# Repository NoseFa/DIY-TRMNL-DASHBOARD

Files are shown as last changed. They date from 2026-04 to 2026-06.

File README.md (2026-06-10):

# Nordic TRMNL

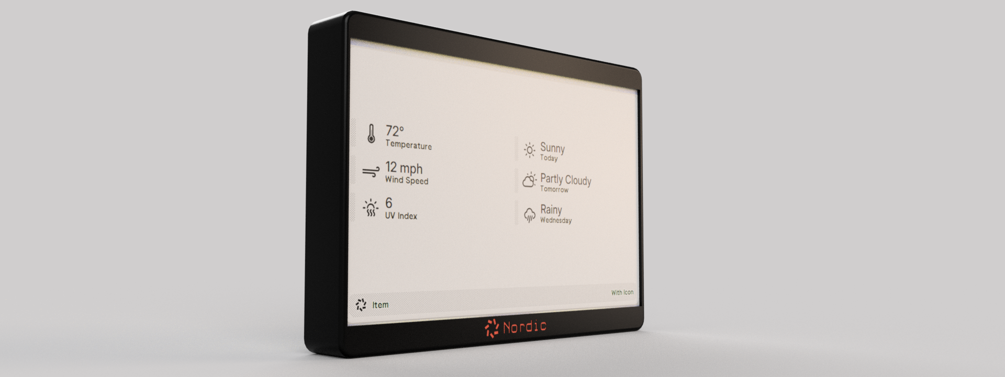
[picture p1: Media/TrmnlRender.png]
Nordic TRMNL 3D render of the nordic TRMNL


A diy dashboard that is built with the TRMNL software in mind. Can display stuff like the your calendar, reminders or the public transit schedule. This repo is only for the hardware side. The TRMNL docs were a huge help in the design process and most of the electronics are based on their suggestions. This project was designed as a part of the Hack Club hardware hackathon FALLOUT where people make hardware projects and get a chance to go to Shenzhen, China. More info available here [Fallout](https://fallout.hackclub.com)!

## Parts

- SEEED studio 7.5" monochrome e-ink display [SeeedStudio](https://www.seeedstudio.com/7-5-Monochrome-ePaper-Display-with-800x480-Pixels-p-5788.html)
- SEEED studio ePaper driver board [SeeedStudio](https://www.seeedstudio.com/ePaper-breakout-Board-for-XIAO-V2-p-6374.html)
- SEEED studio XIAO ESP32-C3 [SeeedStudio](https://www.seeedstudio.com/Seeed-XIAO-ESP32C3-p-5431.html)
- 3D printed [Case](./3Dfiles/)
- M2.5x5mm screws [Aliexpress](https://www.aliexpress.com/item/1005011821173994.html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)
- M2.5 Heated set inserts [Aliexpress](https://www.aliexpress.com/item/1005006838108683.html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)

## Build guide

If you are using the same components the Cad files are here [3D files](./3Dfiles/CaseFiles/). [Case folder](./3Dfiles/CaseFiles/) has ready to print files that have the case parts. Use these if you are just printing the case. The case is designed to be printed in two halves which then are screwed together for the final build. The [full project folder](./3Dfiles/FullProject) has the whole Fusion project including the driver board PCB, ESP-32 and the display. You might want to use this if you want to edit the files. You might also want to adjust some tolerances if your printer has issues with these or you are using different inserts for example. My printer is a pretty budget FDM printer and it didn't have any issues. The two pieces most likely might not fit on the printer at the same time so you might need to print them seperately. I have also included 3D printer files for the [logo pieces](./3Dfiles/CaseFiles/FrontLogo/). If you want to print these seperately. This is what I did because I dont have a multi color printer (This is just if you want the front logo highlighted).

You should start off by printing the [Display holder](./3Dfiles/CaseFiles/DisplayHolder/) and the [Main frame](./3Dfiles/CaseFiles/MainFrame/). These parts are required. The display holder can be printed without supports but the main frame will most likely require them in some areas depending on the orientation you print in. Then you might want to print the logo as well [Logo](./3Dfiles/CaseFiles/FrontLogo/).

After getting the parts printed you can attach the ESP32 to the driver board using the header pins. The display should be installed in the display holder first. You should then install 4 heated inserts in each of the corners of the display holder. The print should have ready made holes for them.

You can then take the main frame and install the heated inserts for the driver board pcb (there are 4 holes). You can then screw in the pcb with the 2.5mm x 5mm screws. If you want to you can add some small pieces of double sided tape to the highlighted corners in the screenshot below. This can make the display fit better but isn't required for the build to work.

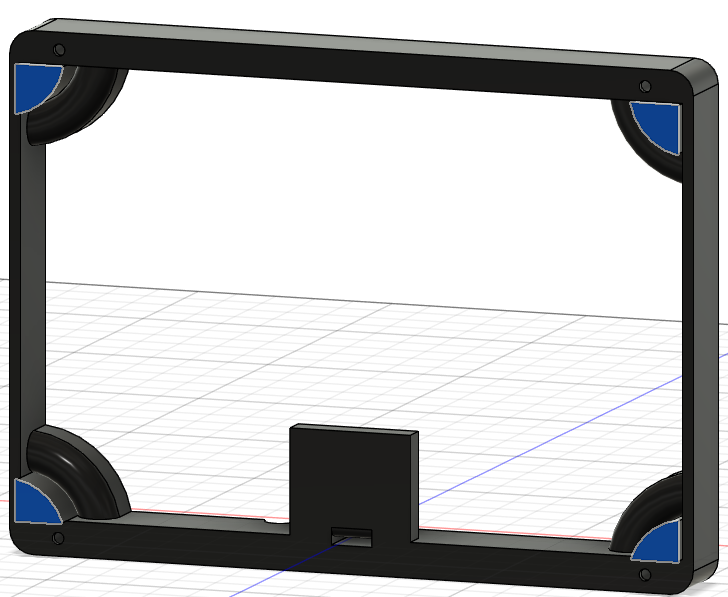
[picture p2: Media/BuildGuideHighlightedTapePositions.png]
Highlighted positions for the double sided tape


After this you can attach the body parts together using the same 2.5mmx5mm screws (you might need a screwdriver with a narrow end to fit) remembering to route the display cable through the slot for it below the pcb holder. If you printed the logo you can attach it using super glue or just press fitting them together.

Now the physical build is done and you can move onto software. You should check the software section for more detailed software instructions. As a TL;DR You can pretty much just use [this tool](https://trmnl.com/flash) to flash the firmware. You should still check the software section for detailed instructions.

If self-hosting follow the guide in the software section or the offical TRMNL guide available in the TRMNL dev [docs](https://docs.trmnl.com/go/diy/byod-s).

If you plan on using TRMNL servers. After flashing the firmware you have to buy access and then claim the device through the site. [Claim your device](https://trmnl.com/claim-a-device).

For mounting the device I used command strips / double sided tape. I think this is better than screws for example because the device is light enough to just be held up with double sided tape. Also making the device attach with screws reliably would be harder and in my opinion overkill.

If you don't have an outlet / power source next to you mounting point you can use a battery. The Seeed e-paper driver board comes with a JST connection to connect a battery and it seems to be pretty easy. I didn't need this since I have an outlet at the perfect spot to plug into and an extra usb-c power source laying around.

## Why does this exist ?

This was a personal project made to make my day to day life easier. Every morning when I wake up I first look at my school schedule then check the time and finally the weather. Of course because of early mornings I usually had to check atleast twice.

So I looked for solutions of displaying the weather while also being able to do other stuff like displaying a calendar or schedule. So I found the TRMNL which was close to a perfect solution for my problem. Unfortunately the official TRMNL OG was a bit too expensive and had some features I didn't need like a battery. So I decided to make my own. My goal for this project was to make something actually useful for me. For this it needed to do atleast 3 things.

1. Show me important information like the weather without having to look at my phone.
2. Wall mountable.
3. Not need to be charged or managed alot after creation.

This was also a project made for Hack Club [Fallout](https://fallout.hackclub.com)! So that was also a motivation behind this project.

## Software

For the software I will start off with explaining the installation process and then move onto some extra info about it.

### Installation

Start off with plugging in the ESP-32 to you computer. You can then open the tool [available here](https://trmnl.com/flash). You can pick the "Seeed studio (XIAO 7.5" ePaper panel)" because it uses the same controller the ESP32-C3.

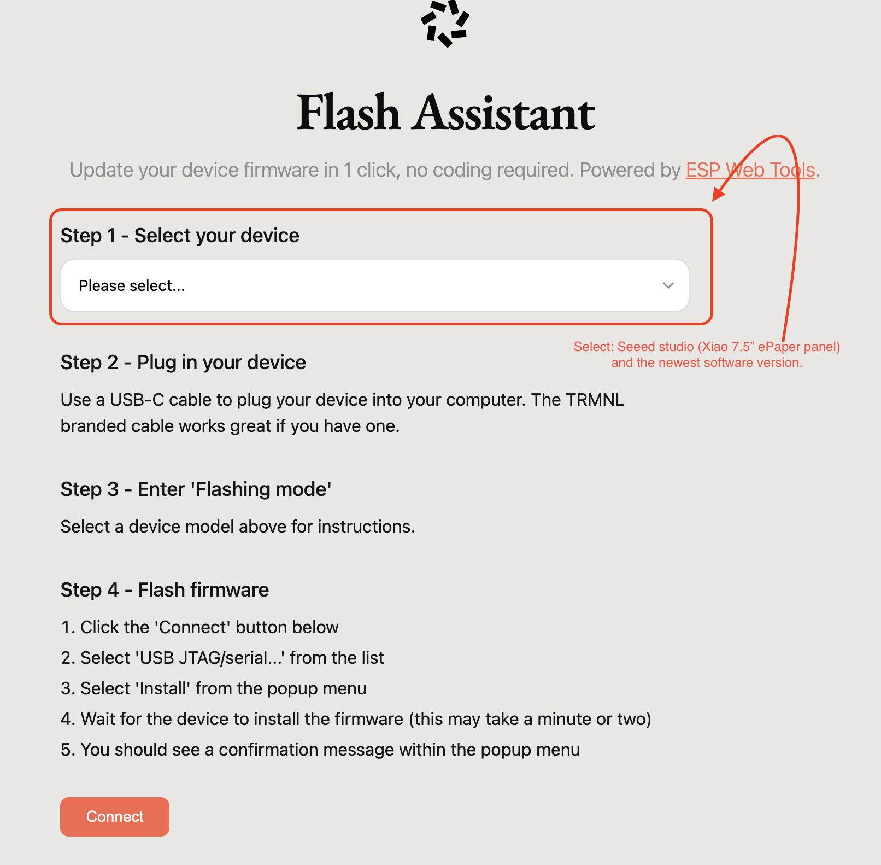
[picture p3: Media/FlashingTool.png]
Flashing tool A screenshot from the flasing tool


To enter the ESP-32 into flashing mode you should plug it into your computer and hold down the BOOT button. This is the left button when looking at the board with the USB-c port pointing upwards. After this it should be visible in the USB JTAG/serial menu of your browser if you are using the web tool. After flashing the software to the ESP-32 you are done with the board and should move onto the configuring the server side. Incase you can't use the web tool for some reason you can find more detailed instructions on [TRMNL's software GitHub page](https://github.com/usetrmnl/trmnl-firmware). This includes compiling the code yourself and having to combine .bin files and flashing them. This is mostly meant for developers and you shouldn't need it if you use the web tool. The .bin files are also available on the terminus dashboard if you are self-hosting.

The next steps you need to do is setting up the server and syncing it to the display. If you plan on self-hosting (this means running a docker container with the TRMNL server on your own hardware like a RPI or a home server etc.). This option is a little bit more advanced compared to using TRMNL's servers and I would suggest that if you can afford it buying the licence to use TRMNLs servers. It will most likely worth it just to skip the hassle with plugins etc. More about the differences in the next section.

### Buying access

For buying access you can navigate to [the TRMNL site store](https://shop.trmnl.com/products/byod). Here you can buy access / a license to use TRMNL servers for your display. The server is responsible for compiling all the data from different sources and then sending a photo that the device can render to your display. This is the easier option and after flashing the firmware on your ESP-32 you should just be able to navigate to [The Claim your device page](https://trmnl.com/claim-a-device). Here you should input the data needed this includes account information and information about your BYOD license order. After claiming the device by connecting to the wifi hotspot of the TRMNL then using the login functionlaity to input your wifi information for the TRMNL to connect. Then the display should display a friendly id and you can input that to your dashboard and it should start working. After this you can start setting up what you want to see on your TRMNL in a playlist. You can for example use [this recipe](https://trmnl.com/recipes/150460) by [Daniel Sitnik](https://github.com/danielsitnik/) to display the weather.

I haven't setup my device this way since I self-hosted and the setup flow can change so for the most up to date information you can check [the TRMNL site](https://docs.trmnl.com/go/diy/byod). Some of the setup flow was behind authentication and you need a licence for it so this guide might be missing a couple steps but the main points are outlined here.

### Self-Hosting

> [!NOTE]
>Self-hosting does require a lot more setup compared to buying access. Currently there are no ways of self-hosting that include the plugins made for the TRMNL hosted solution in a one click add way. Projects like Terminus are trying to make this better but they still aren't fully compatible and the plugin support is one of the major things still missing. I would suggest the hosted solution to everyone who isn't already experienced in home labbing and comfortable with self hosting services. If you want the easy one click installation of different screens and plugins Terminus is not there yet. Hopefully will be soon and that is the end goal for it.

For self-hosting I will explain what I did in order to get it working. There are multiple OSS ways you can implement a self-hosted version of a TRMNL server. I used [Terminus](https://github.com/usetrmnl/terminus) which is the most popular way of doing this and is the closest to the hosted solution in terms of features. The Terminus project is still in beta and not 100% equal to just buying TRMNL access. They do have extensions and they are working on making the importing plugins possible from the hosted version. It still isn't fully inline with the TRMNL hosted solution.

For me since I already have a home server I chose this route to save some money and maybe learn a thing or two. There are already existing guides by on [the Terminus GitHub page](https://github.com/usetrmnl/terminus) and [in the TRMNL Help forum by Mario](https://help.trmnl.com/en/articles/12263392-connect-your-device-to-terminus-byos). Mario's guide covers how to sync your device to a server and the GitHub guide covers setting up the server itself. I have tried to summarize what I did and the main points here but these can help you if you want to know more about this or are running a different setup etc.

So for starters you should have something to host this on. I used docker compose on my unraid server. I first installed the compose manager plus plugin from the unraid community app store. Then I just inputted the docker compose file available in [the terminus repo](https://github.com/usetrmnl/terminus/blob/main/compose.yml). A .env file should be created automatically. You can view the [Terminus github page configuration section](https://github.com/usetrmnl/terminus/blob/main/doc/configuration.adoc). It has great information on what the .env file includes and what each variable means and does.

Then I accessed the webui which was available at `http://HostedIp:2300`. Here I created a new user and password. Then I was able to access the web dashboard. It looks like this

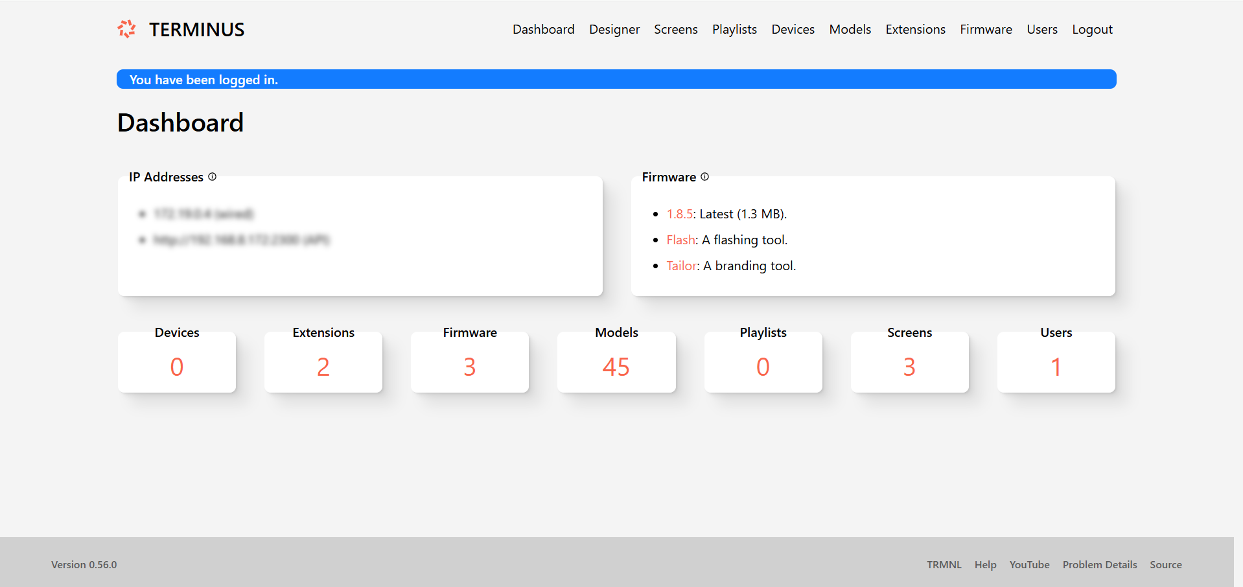
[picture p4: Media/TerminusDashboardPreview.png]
Terminus Dashboard The web dashboard for Terminus


Here you can navigate interface to browse different extensions. Some of them can be directly installed and some need some extra configuration. For community made extensions you can open the extensions menu and click Gallery. You can use the devices section to see statistics from your device and for example the offical TRMNL devices report battery status here. In the devices section you can also configure other stuff about the device like update frequency, sleep states and what playlist is currently visible.

I have included a customized version of [the daily weather plugin / recipe](https://trmnl.com/recipes/150460) that I have modified to work on the self-hosted version. You can find it in the [software folder](./Software/software.md) (All credit goes to the original creator [Daniel Sitnik](https://github.com/danielsitnik/) and I just edited their code to work with the self-hosted version). I have also included some info about what I changed to get it to work in the [Software.md file](./Software/software.md) as well as installation instructions.

After flashing the software to the TRMNL itself. You can then connect it to power and see the screen of the TRMNL display you should connect to the wifi hotspot on your phone and use the sign in functionality on your phone to view the setup web portal (kind of like what you need to do on some public wifis to get online). You can navigate to the advanced software section and click custom server. You should input the local address which should be `http://HostedIp:2300` to the api server input as well as your wifi credentials. If everything is good you should see a "Welcome to Terminus" screen rendered.

Even though the self-hosted setup will work I might still move onto the hosted solution just for the plugins / recipes. The extensions in Terminus do get close but still aren't perfect and need some work to get working. I hope they can get the one click importing and exporting working soon. So as a suggestion if you have the money I would buy access to the TRMNL hosted servers just for the ease of use and the ecosystem around the hosted environment. Still I have attached [the daily weather plugin / recipe by Daniel Sitnik](./Software/extension-daily_weather.zip) incase you do end up self-hosting and want to see what I modified to make a normal recipe/plugin work.

## Why it's a bit better ?

So my diy Nordic TRMNL is made to be wall mountable first. This makes it easy to blend in to the environment. Also buying the components directly and self hosting the server makes the whole package a little bit cheaper. I am still thankful that TRMNL decided to open source the software and make the product diyable and self-hostable. So there are somethings that I think my TRMNL does better. This was also a good learning experience in self-hosting.

## Wiring

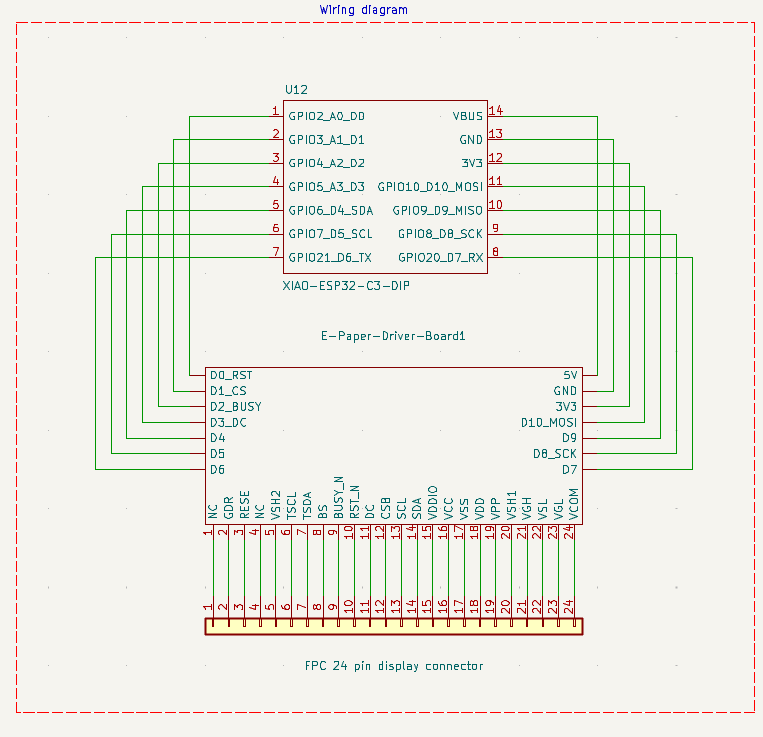
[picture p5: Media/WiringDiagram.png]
Wiring diagram Kicad Wiring diagram


I made a wiring diagram of the connections in KiCad. Most of the connections are just plug and play and using the sockets that are on the driver board the connections are pretty simple. Still there is a wiring diagram if it's needed. Also available as a [kicad schematic](./WiringDiagram/NordicTrmnl.kicad_sch).

Here is another wiring diagram with pictures that shows how they attach together IRL. This might be easier to read.

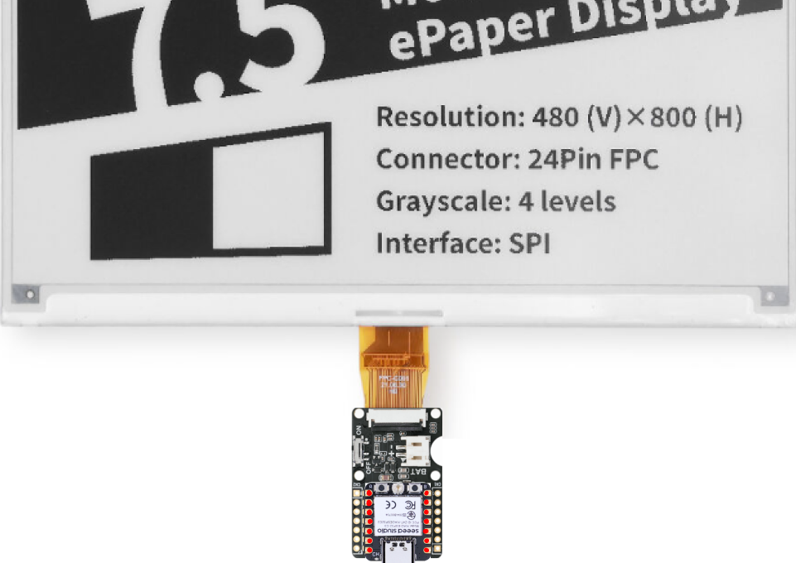
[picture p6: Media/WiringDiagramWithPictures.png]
Wiring diagram Wiring diagram with pictures


## Zine Page

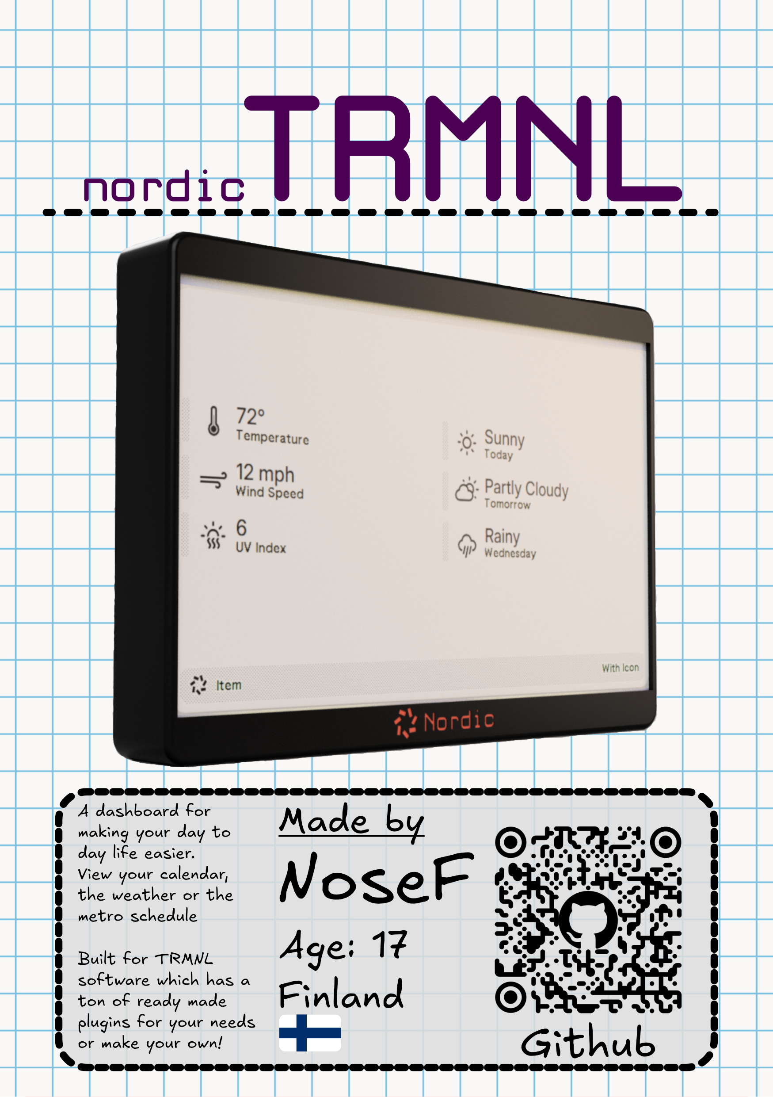
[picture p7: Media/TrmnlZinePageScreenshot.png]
Zine Page


## Excalidraw / Notes

I used excalidraw during my design process. The mind map screenshot attached has most of my design notes. The mind map is available as an [excalidraw file](./Excalidraw/Notes.excalidraw) for a better viewing experience.,
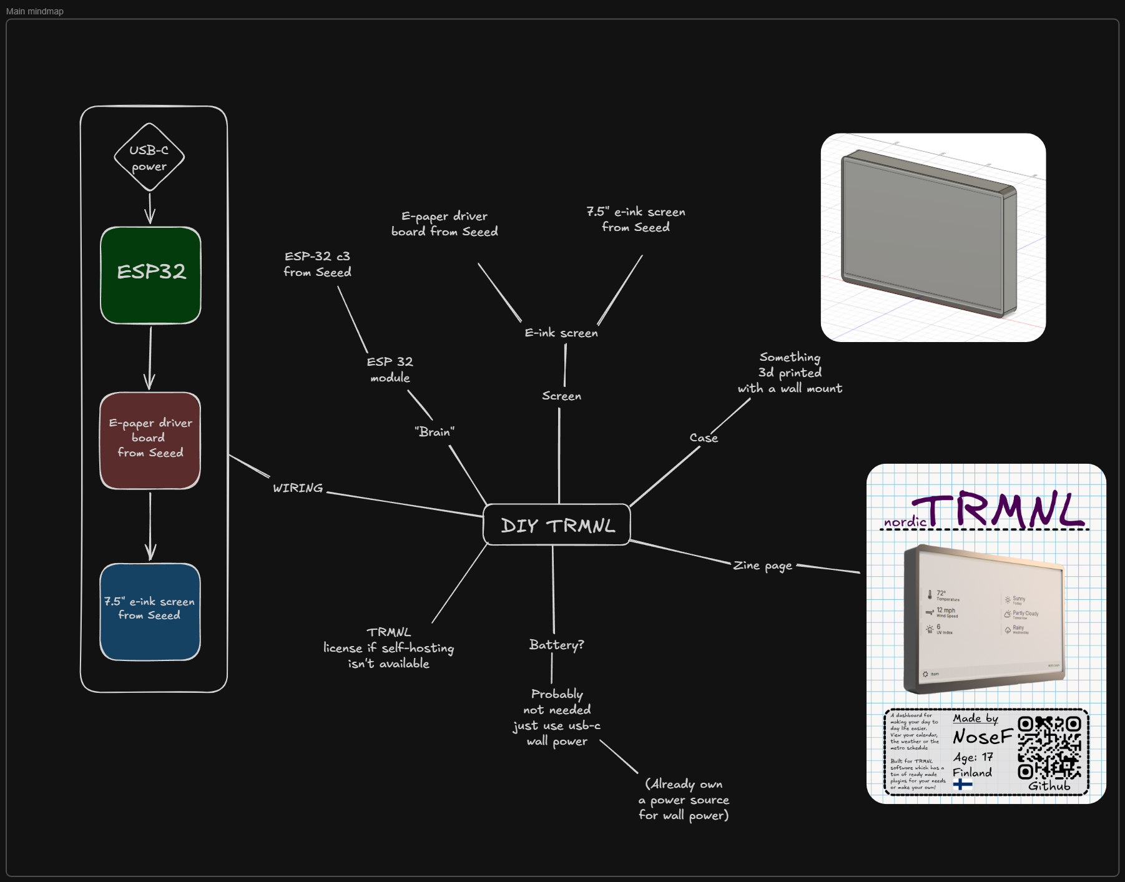
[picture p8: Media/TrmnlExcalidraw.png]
Excalidraw
.

Bill of Materials available here: [BOM](./BOM.csv). (BOM doesn't include the cost of 3D printing since I did it with my own 3d printer. Also the price of double sided tape isn't included since I already had it around.)

## Pictures

Here are some more renders of the project.

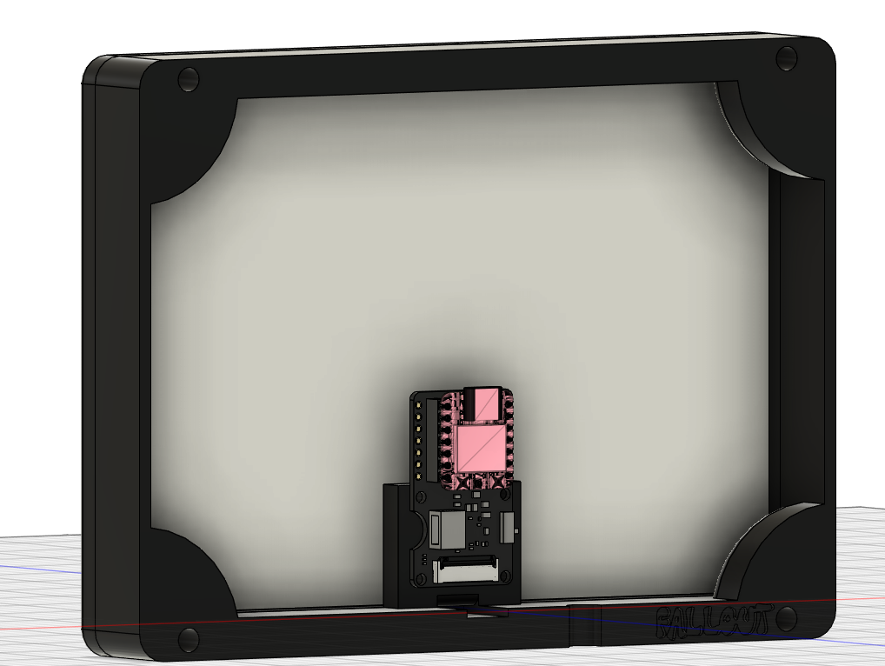
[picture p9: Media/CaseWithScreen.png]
Case with PCB

Case from behind with screen and PCB.

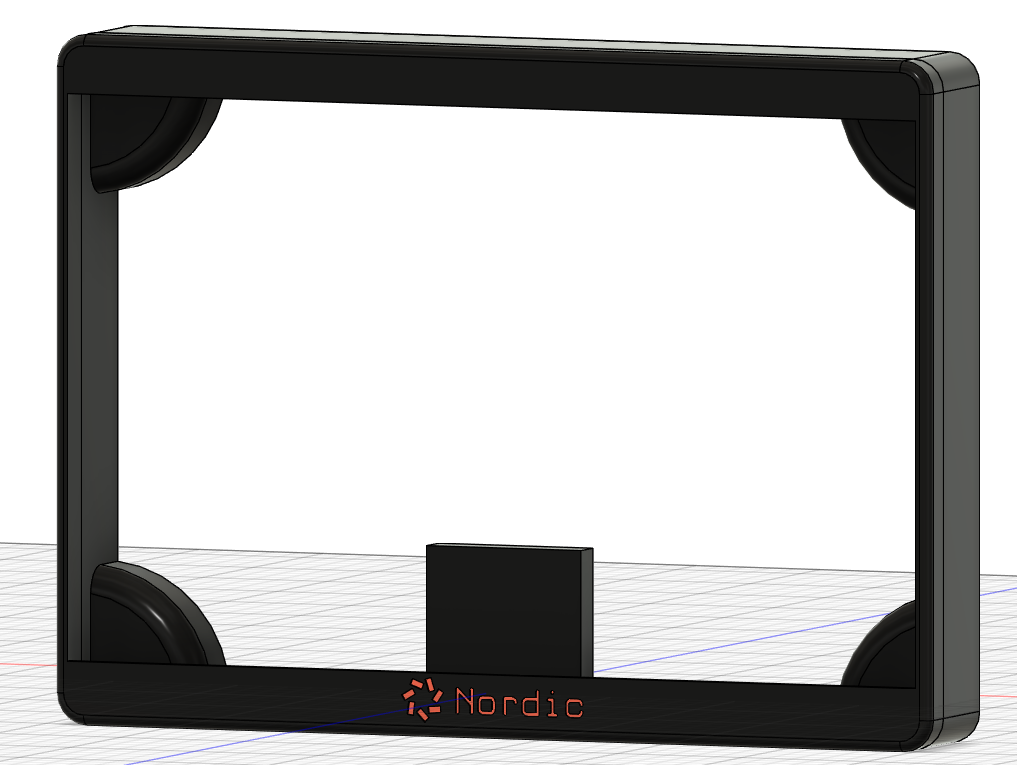
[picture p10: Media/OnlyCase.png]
Case Case without PCB

Case from the front without screen and PCB.

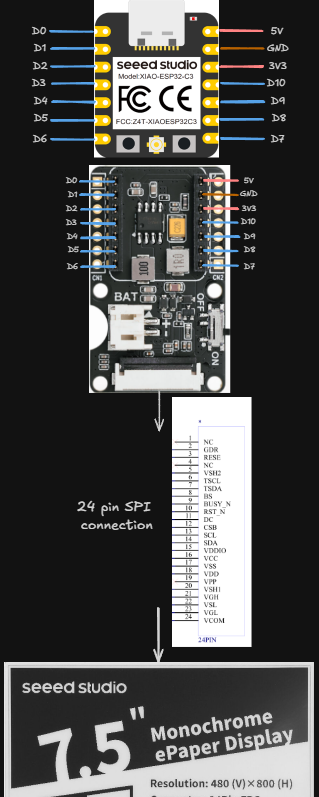
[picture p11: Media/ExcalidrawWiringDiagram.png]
Wiring diagram Simple wiring diagram


Simple Excalidraw Wiring diagram. I made this before the "real one" in Kicad.

## Acknowledgements

Thanks to Hack Club and the Fallout event for making this project possible. If you want to view the project I made for Fallout including journals you can view it [on the event page](https://fallout.hackclub.com/projects/828).

Thanks to TRMNL for open sourcing their software and making custom devices and self hosting possible.

Thanks to Terminus for their self-hosted server software.

Thanks to [Daniel Sitnik](https://github.com/danielsitnik/) for making the Daily Weather recipe I modified.

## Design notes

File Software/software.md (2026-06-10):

# Weather extension

This extension was made by [Daniel Sitnik](https://github.com/danielsitnik/). I modified some of the names of the variables just to match the syntax for terminus. You will probably need to modify the URL provided by the template. You will need to set your prefered temperature units and location using longitude and latitude. When you install the extension these will be set to the once I used so you will want to modify them. You can install this extension just by navigating to the extension section and clicking the import extension button (highlighted in the screenshot).

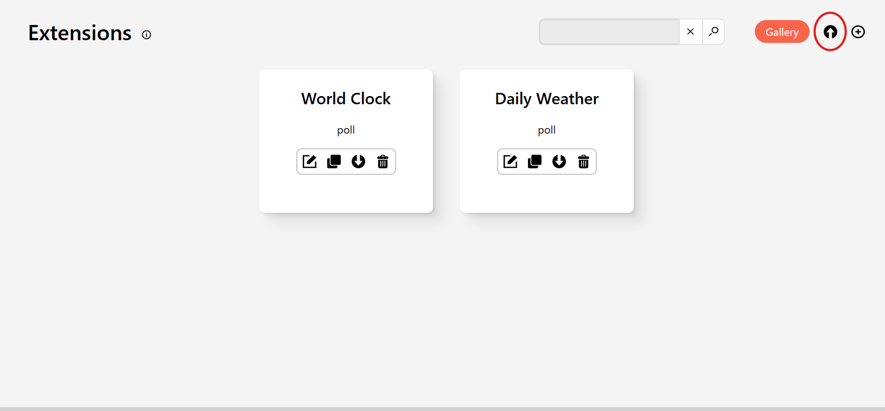
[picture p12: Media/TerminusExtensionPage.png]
ExtensionsPage Extension page in Terminus


Then you can simply pick the [.zip file](extension-daily_weather.zip) and it should install automatically. ONCE AGAIN THIS EXTENSION IS NOT MADE BY ME AND JUST EDITED TO WORK WITH TERMINUS!!!

After this you can add the screen to a playlist and it should be come visible on your TRMNL.

## What I changed ?

To get the extension to work I had to add the `source_1.` prefix to variables that used the open meteo api and I had to remove the `source_1.` prefix from places it already existed but that didn't actually use it as a source. So I removed it from the sources for the pictures. This same basic concept can be used to convert almost any of the extensions. 
I didn't end up making a calendar extension since the ones that existed didn't work on Terminus yet at all or I didn't have the technical skills to make them work with my calendar setup. Terminus also didn't seem to accept `.ical` files as sources. This might have been just a problem with my skill (I'm not super good at coding and software stuff) but it seemed like too large a hassle for now. Terminus is being updated so maybe soon importing will be just onclick.

You can view the raw software files in the [Unzipped software folder](./UnzippedSoftware/). The changes I made are to the [Template.html.liquid](./UnzippedSoftware/template.html.liquid) the [configuration.yml](./UnzippedSoftware/configuration.yml) hasn't been edited. ONCE AGAIN THIS EXTENSION IS NOT MADE BY ME AND I JUST EDITED THE TEMPLATE FILE TO WORK WITH TERMINUS!!!

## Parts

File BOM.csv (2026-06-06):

 | Price | Link | Notes
SEEED Studio XIAO ESP32-C3 | 4.99€ | https://www.seeedstudio.com/Seeed-XIAO-ESP32C3-p-5431.html | I have headers available so I will solder them myself but if you don't you should look into pre-soldered. Shipping is calculated with buying all Seeed components on one order and is displayed below
SEEED studio ePaper driver board | 4.99€ | https://www.seeedstudio.com/ePaper-breakout-Board-for-XIAO-V2-p-6374.html | Shipping is calculated with buying all Seeed components on one order and is displayed below.
SEEED studio 7.5" monochrome e-ink display | 30.99€ | https://www.seeedstudio.com/7-5-Monochrome-ePaper-Display-with-800x480-Pixels-p-5788.html | Shipping is calculated with buying all Seeed components on one order and is displayed below.
Heat set inserts M2,5xL3mm 100pcs | 0.88€ | https://www.aliexpress.com/item/1005006838108683.html?curPageLogUid=GGTl9fJBIg9O | Only 8pcs needed but I couldn't find smaller packages
M2.5 x 5mm screws. 50pcs | 0.88€ | https://www.aliexpress.com/item/1005011821173994.html?curPageLogUid=PxbGNUoUDbsP | Only 8pcs needed but I couldn't find smaller packages
TOTAL inc. shipping | 57.92€
NOTE!
Shipping for the Seeed products will be 15.19€ all together inc. duties.
Both aliexpress products have free shipping.
I will be self 3d printing so the price of the case isn't included.

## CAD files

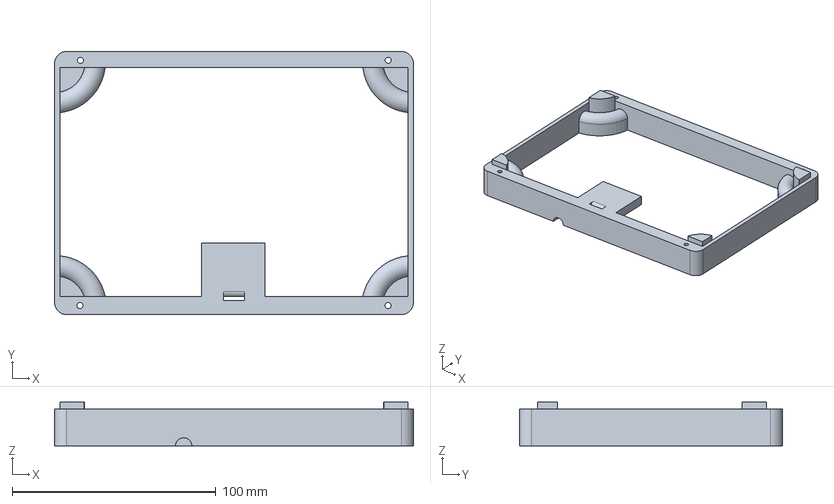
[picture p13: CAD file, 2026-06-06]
3Dfiles/CaseFiles/MainFrame/MainFrame.step
176.2 x 129.2 x 21.5 mm

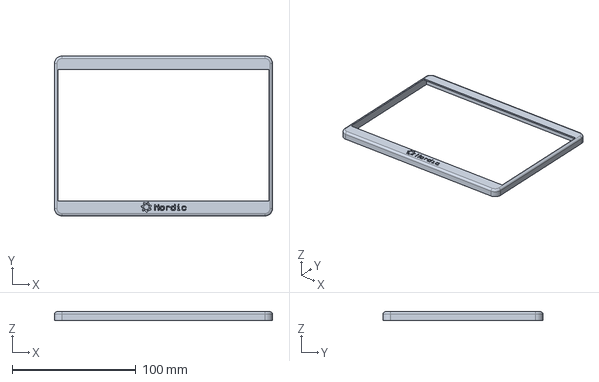
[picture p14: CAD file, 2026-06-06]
3Dfiles/CaseFiles/DisplayHolder/DisplayHolder.step
176.2 x 129.2 x 7.00 mm

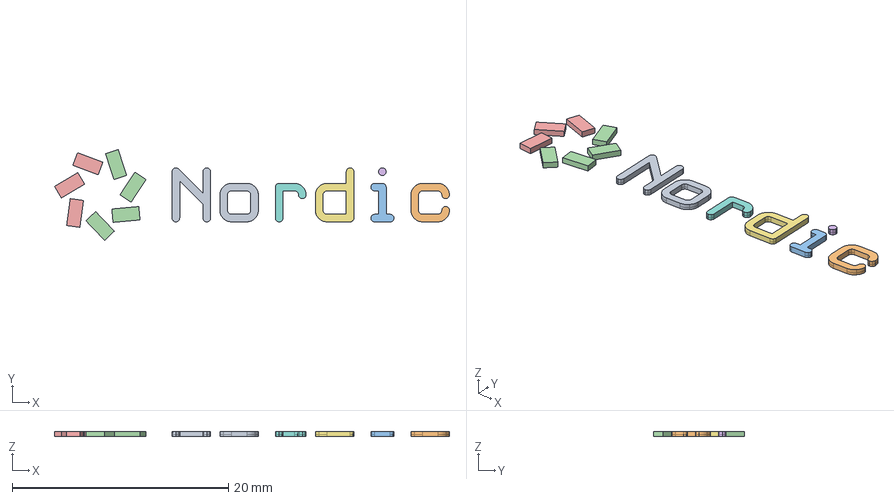
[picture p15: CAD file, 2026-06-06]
3Dfiles/CaseFiles/FrontLogo/Logo.step
36.5 x 8.40 x 0.5 mm

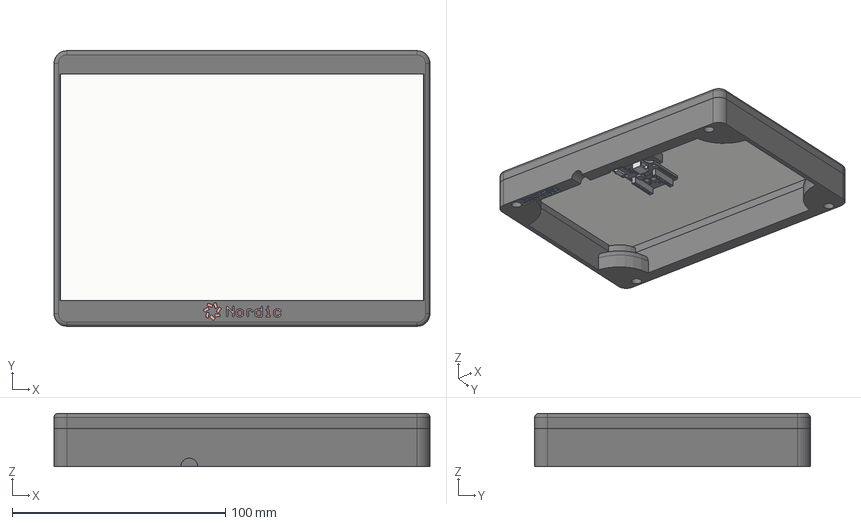
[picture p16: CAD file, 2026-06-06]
3Dfiles/FullProject/NordicTRMNL.step
176.2 x 129.2 x 25.0 mm

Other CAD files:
3Dfiles/CaseFiles/DisplayHolder/DisplayHolder.3mf
3Dfiles/CaseFiles/FrontLogo/Logo.3mf
3Dfiles/CaseFiles/MainFrame/MainFrame.3mf
3Dfiles/FullProject/NordicTRMNL.f3d

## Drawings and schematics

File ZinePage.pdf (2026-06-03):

# nordicTRMNL

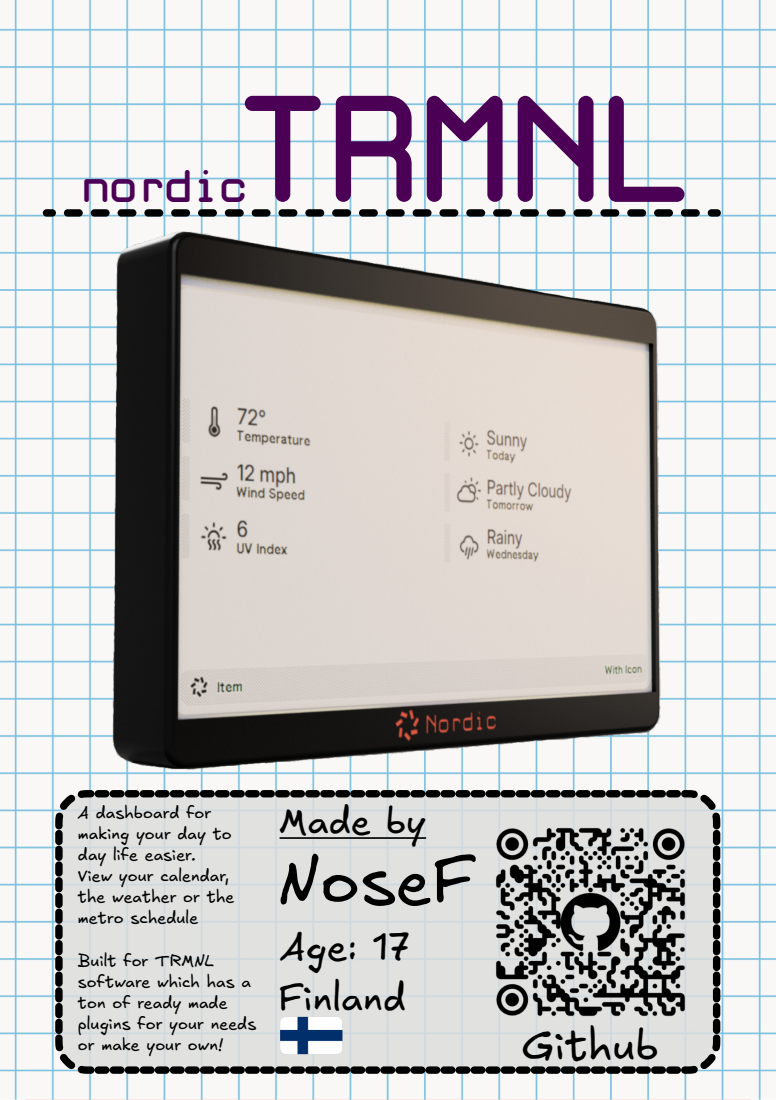
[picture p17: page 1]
Github

Made by A dashboard for
making your day to
NoseF
Age: 17
Finland

day life easier.
View your calendar,
the weather or the
metro schedule

Built for TRMNL
software which has a
ton of ready made
plugins for your needs
or make your own!

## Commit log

2026-03-26 Added seeed studio parts to readme
    Added parts list to include display, esp32 and driver board
2026-04-06 Added excalidraw board
2026-04-06 Added BOM and changed README
    - Added BOM with parts, links and prices.
    - Added info about software.
    [TRMNL BOM.csv]
2026-04-06 Added more information about the project to README - Added a software section and a build guide - Changed the name of the BOM.csv to match the name suggested by Fallout.
    [BOM.csv]
2026-04-07 Added 3d files Added files for 3d printing the case.
    [NordicTRMNL.f3d, NordicTRMNLCase.3mf, NordicTRMNLCase.obj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]
2026-04-07 Chnaged 3d files and added new data to the BOM
    [BOM.csv, NordicTRMNL.f3d, NordicTRMNLCase.3mf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]
2026-04-07 Added info about building with heated inserts.
2026-04-07 Added info about mounting to README
2026-04-09 Wiring diagram - Added information about the wiring diagram and added the kicad schematic file for it. - Addeda picture of the kicad wiring diagram and the excalidraw one just incase.
    [NordicTrmnl.kicad_sch]
2026-04-09 Added excalidraw board as a .excalidraw file.
2026-04-09 Added a new wiring diagram - Added another wiring diagram that makes seeing how to assemble the TRMNL easier.
    [BOM.csv]
2026-04-13 Edited 3d files to include attachment screws. - Edited the 3d files to make attaching the display possible.
    [NordicTRMNL.f3d, NordicTRMNLCase.3mf, NordicTRMNLCase.obj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]
2026-04-13 Edited 3d files. - Added screw holes to attach the pcb holder.
    [BOM.csv, NordicTRMNLCase.3mf, NordicTRMNLCase.obj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]
2026-04-13 Made sure the full fusion file is up to date
    [NordicTRMNL.f3d]
2026-04-20 Added some better tolerances.
    - Noticed that I had forgotten to add tolerances to some parts.
    - Modified all 3d files to include better tolerances (atleast 0.2mm)
    - Added a .step file for the full project.
    [NordicTRMNL.f3d, NordicTRMNL.step, NordicTRMNLCase.3mf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]
2026-05-02 Added software info.
    - Added software info to README.md.
    - Added info about self-hosting.
    - Added info about how to flash the software to the device.
2026-06-03 Updated readme with better instructions and photos
    [BOM.csv]
2026-06-06 Updated readme to read better
    [BOM.csv]
2026-06-06 Added better building instructions.
    [NordicTRMNL.f3d, NordicTRMNL.step]
2026-06-06 Added new 3d files
    - Added new 3d files including case and Full Project
    - Changed README to have working links.
    [DisplayHolder.3mf, DisplayHolder.step, Logo.3mf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]
2026-06-06 Fixed part amount needed in bom
    [BOM.csv]
2026-06-09 Corrected a mistake in the Readme
    - Corrected my mistake of thinking the OG TRMNL didn't have a wall mount.
